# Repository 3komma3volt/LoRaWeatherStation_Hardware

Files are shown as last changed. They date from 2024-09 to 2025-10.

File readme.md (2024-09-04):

# LoRa Weather Station

The project was born for testing LoRa devices an has grown to a small weather station ecosystem.
Since August 2002, there are 6 station outside running without any maintenance. 

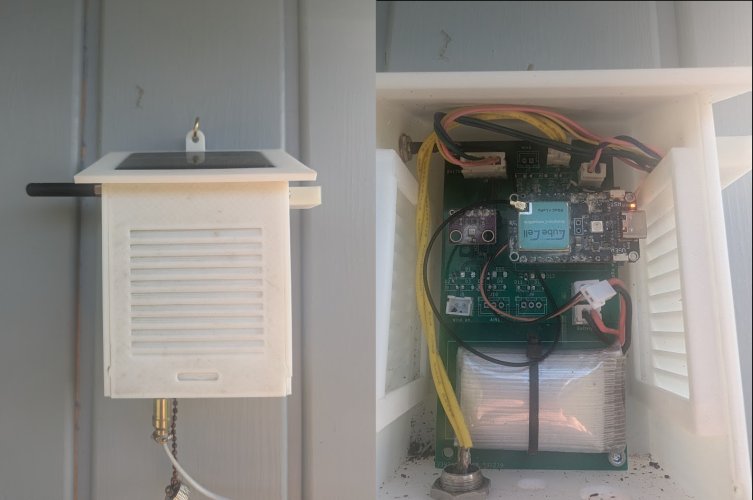
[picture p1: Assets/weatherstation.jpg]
Station


## Features

 - Completely 3D printed main body
 - Modular with optional extension
 - Simple PCB which can be hand assembled
 - Stations can be equipped with sensors as needed, they don't have to be the same kind
 - Using TheThingsStack for receiving data
 - Storage and analysis of data using a PHP framework (other repository)

## Housing

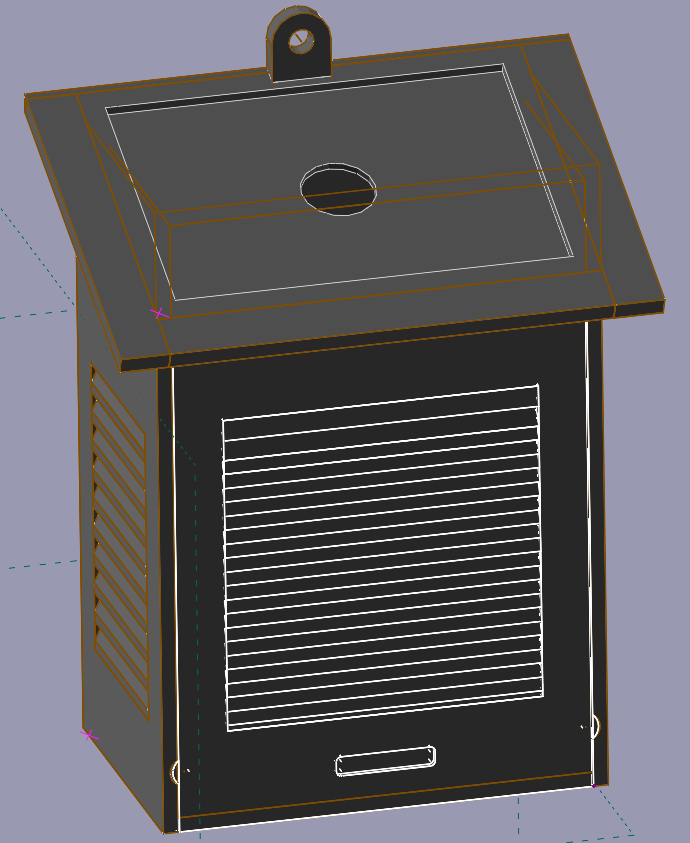
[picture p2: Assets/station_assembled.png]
Rendering


The main housing consists of:
 - Main housing
 - Front door
 - Sensor cover **or** light sensor mount
 - 2x side dust filter fixture
 - Front door dust filter fixture

On the sides and in the front door, there is the possibility to mount some 3mm fleece filters to prevent dust going into the housing and keep bugs out. A disadvantage is, that the inside gets a bit hotter if exposed to the sun.
The best mounting position of the station is 2m from the ground facing north and protected from sun exposure (The solar cell will get enough light to charge the battery).
A 80x55mm 7V solar cell is used to charge the battery. The solar cell is glued to the main body using silicone glue. This works great to keep rain out,
On the bottom is a intended breaking point to mount 12mm screw connectors for external sensors e.g. rain sensor or wind direction sensor.
On the left side is a hole for mounting a SMA connector for the LoRa antenna.
The housing can be mounted on a wall using a hook or screw.

## PCB
The PCB is kept simple, so it can be assembled by hand. It has to be screwed into the main body using **M3x8** (or similar length, there is plenty of space for longer screws)

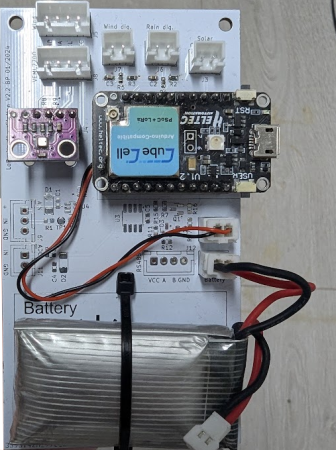
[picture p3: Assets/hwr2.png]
PCB


It is possible to use it just as carrier board, in this case, no component needs to be assembled.
For easier installation, XH connectors are used to connect sensors, battery, solar cell etc.
The CubeCell AB01 board is the brain of the weather station. It has a battery connector on its bottom side. For easier replacement of board or battery, this connector is connected with the PCB which again connects to the battery.
A BME280 board is connected using a standard header, so it can be replaced easily.

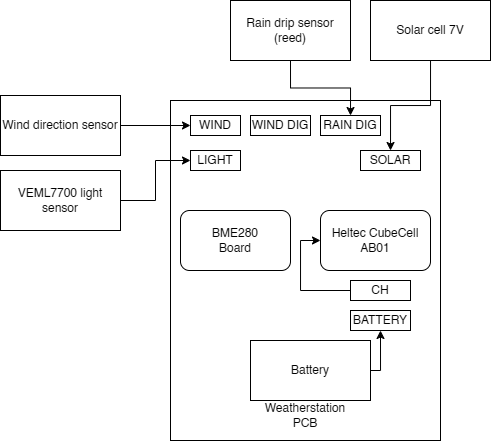
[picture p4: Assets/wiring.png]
Wiring


Two holes on the lower side of the PCB are for mounting a lithium battery using zip ties.
A  standard 1000mA 3.7V LIPO battery works great and never ran out even on cold and dark winter weeks.

## Wind Direction Sensor

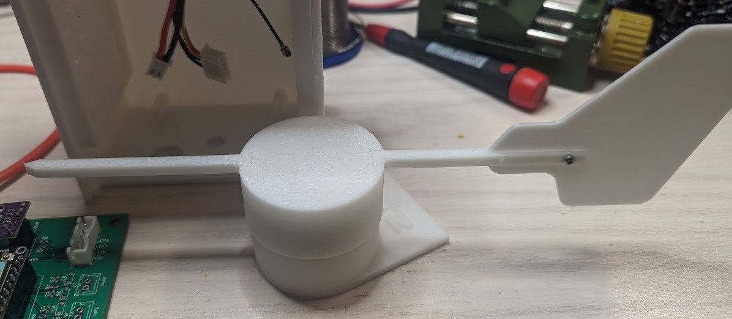
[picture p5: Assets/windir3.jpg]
Winddir


The wind direction sensor uses 8 reed contacts, a I2C port expander, a bearing (**608ZZ**) and a paddle to read the wind direction.

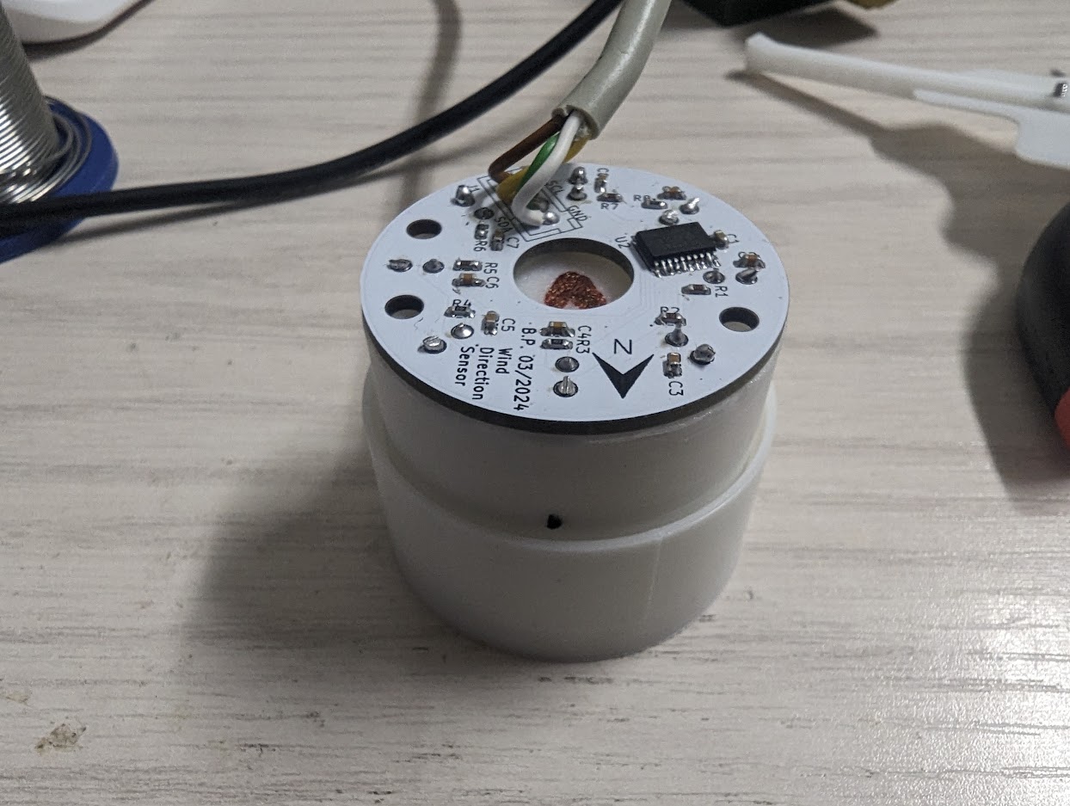
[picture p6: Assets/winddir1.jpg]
Winddir2


Only the expander and some few components need to be assembled.

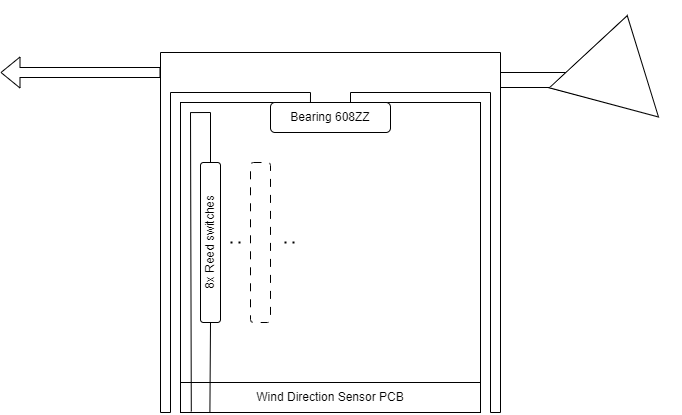
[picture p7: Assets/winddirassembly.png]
WindAssemly


The reed contacts are pushed through the sensor main body, On the upper side, a short wire has to be soldered to the reed contact and threaded through the second hole. The sensor and wire are then soldered to the sensor PCB.
A ⌀6x3mm magnet is glued into the sensor pin.

## Wind Speed Sensor

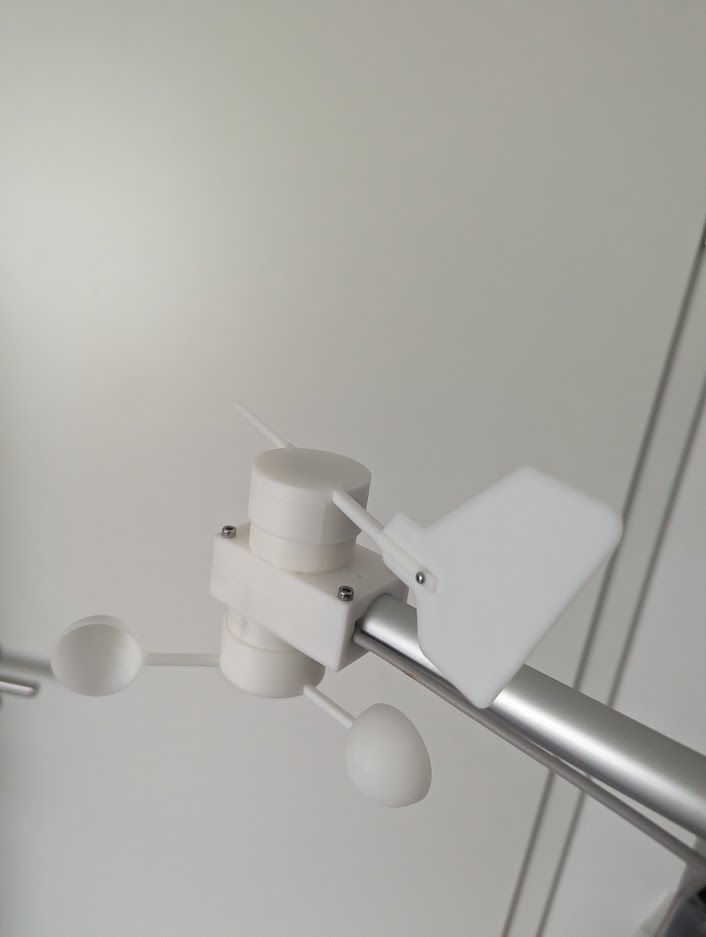
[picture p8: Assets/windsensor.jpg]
WindSpeedAndDir


The wind speed sensor using the same style bearing and manget like the direction sensor. It only consists of one reed contact. 
This sensor is an early alpha state, because the baring is to difficult to move and won't turn on low wind speeds. Maybe switching to a off-the-shelf product for this use case.

## Rain sensor

The 3D printed version of a rain sensor was not reliable enough. A cheap off the shelf sensor which is sold as spare part for weather stations works well. 

## Light sensor

A VEML7700 can be mounted on the side of the main body. For this print the mount and install the sensor within the mount. Fill up the space with transparent silicone. It will get watertight and works well. 

# Firmware
The firmware is made using PlatformIO and the Heltec development platform.
Simply open with VSCode and edit the platform.ini
You can change following build flags:

- ENABLE_RAINSENSOR=0 ; enables the rain drip sensor
- ENABLE_BRIGHTNESSENSOR=1 ; enables the brightness sensor
- ENABLE_WINDDIRSENSOR=0 ; enables the wind direction sensor
- ENABLE_WINDSPEEDSENSOR=0 ; enables the winds speed sensor
- DEBUG_UART=0  ; enables UART data sending for debug purposes

Enable the functionalities as wanted. 

>  Wind speed and direction are BETA!

As brightness sensor the VEML7700 is used. The BH1750 was also tested, but the results with this sensor were not really great. It was not really possible to get the cheap housing with the light dome watertight and several sensors died after a few days. If you want to use the BH1750, some changes in the code are necessary since this parts were removed.

Then hook up with TheThingsStack. There add a new device and get the neccessary data for OTAA transmission. Insert the information in the src/ttnparams.h file.

You probably will need a payload formatter for each individual weather station, since not all stations must have the same functionallity.

Here is a example formatter:

    function Decoder(bytes, port) {
    var temperature = (bytes[0] << 8 | bytes[1]);
	var humidity = (bytes[2] << 8 | bytes[3]);
    var pressure = ((bytes[4]) << 24) + ((bytes[5]) <<  16) + ((bytes[6]) << 8) + ((bytes[7]));
    var battery = (bytes[8] << 8) | bytes[9];
    var unused = (bytes[10] << 8) | bytes[11]; // formally used for battery percent calculation
    var brightness = (bytes[12] << 8) | bytes[13];
    var rain = bytes[14];
  
    var lux = brightness * 2.1504; // Datasheet: Gain 1/8, 25ms integration time
    lux = Math.round(6.0135e-13 * Math.pow(lux, 4) - 9.3924e-9 * Math.pow(lux, 3) + 8.1488e-5 * Math.pow(lux, 2) + 1.0023 * lux);
 
    var sensorSqure = 10.9 * 4.9; // for round rain sensors: sensorSqure = Math.PI * pow(sensorRadius, 2);
    var tipsPer100ml = 100 / 1.5;
    var mlPerTip = 100 / $tipsPer100ml;
    var rainAmount = $mlPerTip / $sensorSqure;
  
    return {
      temperature: temperature / 100,
      humidity: humidity,
      pressure: pressure / 100,
      battery: battery / 1000,
      brightness: lux,
      rain: rainAmount
      }
    }

If a station doesnt have a specific feature, just remove it from the return. The value has to be null to indicate, that the sensor is not available.

Example formatter for the most basic station just with a BME280:

    function Decoder(bytes, port) {
    var temperature = (bytes[0] << 8 | bytes[1]);
	var humidity = (bytes[2] << 8 | bytes[3]);
    var pressure = ((bytes[4]) << 24) + ((bytes[5]) <<  16) + ((bytes[6]) << 8) + ((bytes[7]));
    var battery = (bytes[8] << 8) | bytes[9];
    var unused = (bytes[10] << 8) | bytes[11]; // formally used for battery percent calculation

    return {
      temperature: temperature / 100,
      humidity: humidity,
      pressure: pressure / 100,
      battery: battery / 1000,
      }
    }

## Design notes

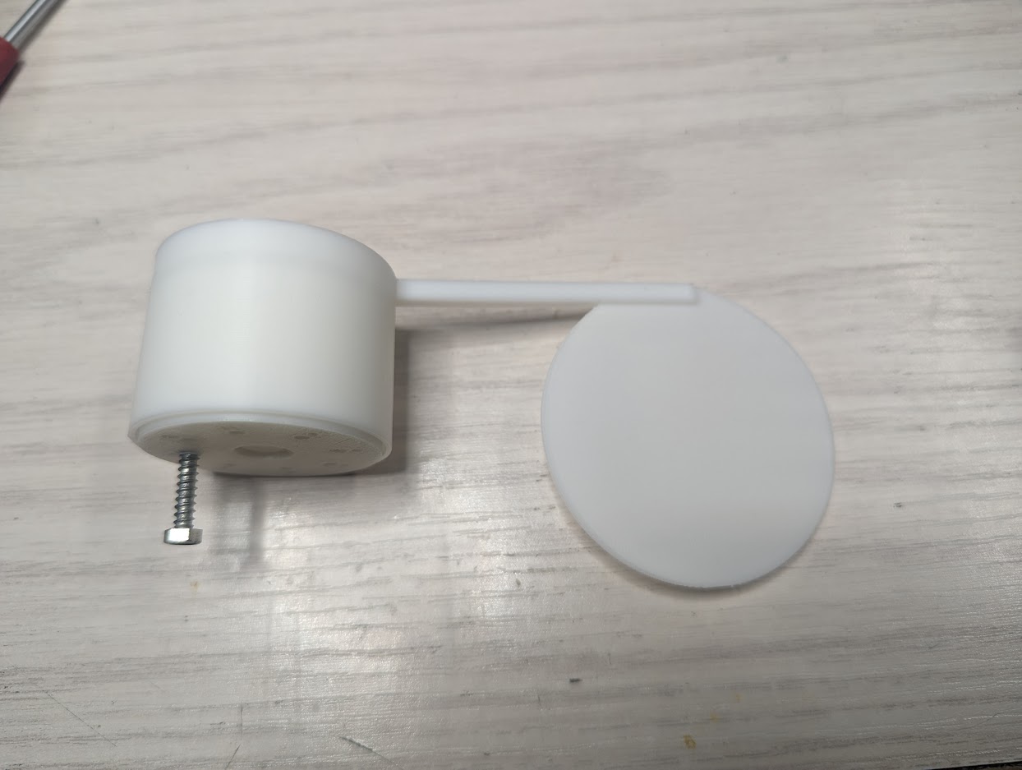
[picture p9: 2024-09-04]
Assets/winddir2.jpg

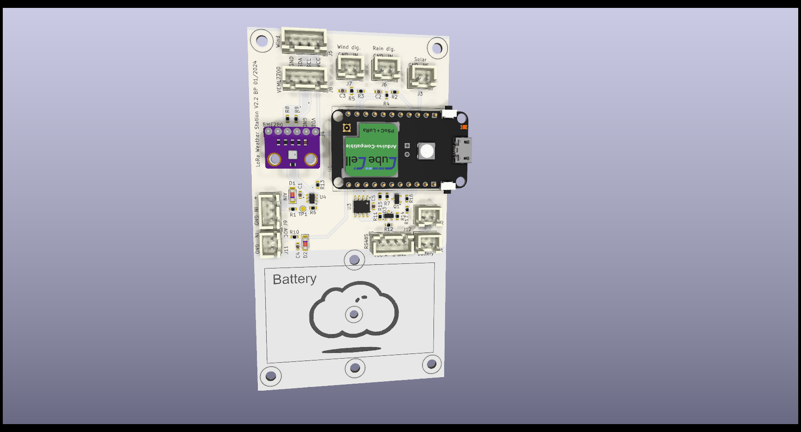
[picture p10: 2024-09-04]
Assets/loraWeatherstation.png

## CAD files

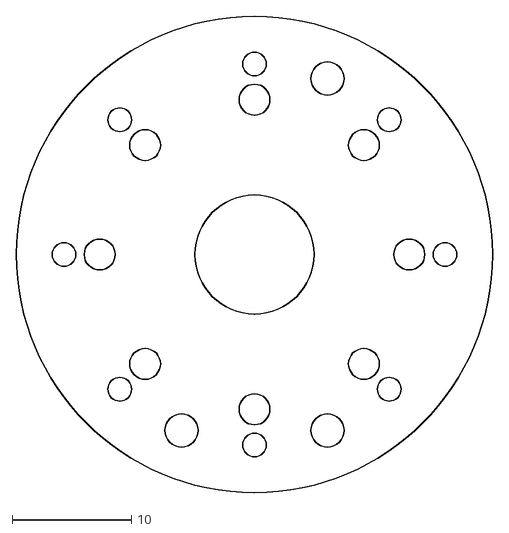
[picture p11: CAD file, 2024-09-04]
Schematics/WindDirSensor/mainbody.dxf
40.0 x 40.0

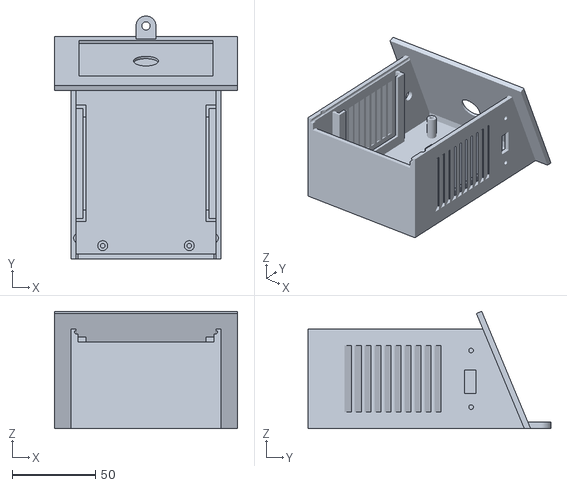
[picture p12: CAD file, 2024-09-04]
CAD/Weatherstation/stl/main_body.stl
110.0 x 146.0 x 70.6

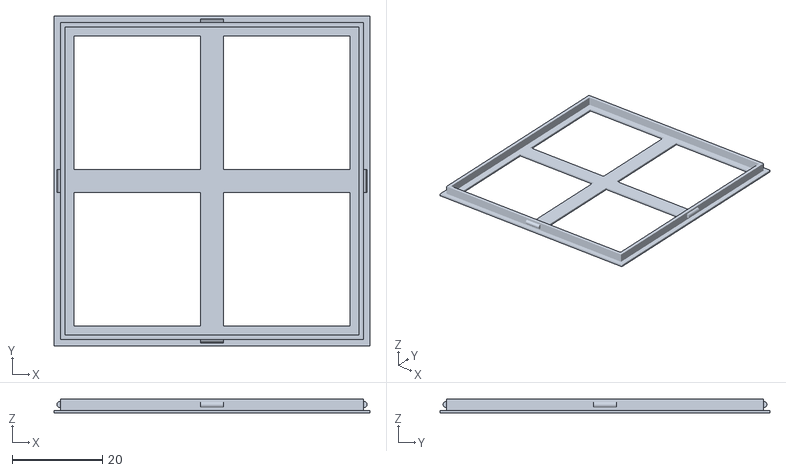
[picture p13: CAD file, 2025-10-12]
CAD/Weatherstation/stl/front_door_filter_fixture.stl
70.0 x 73.0 x 3.10

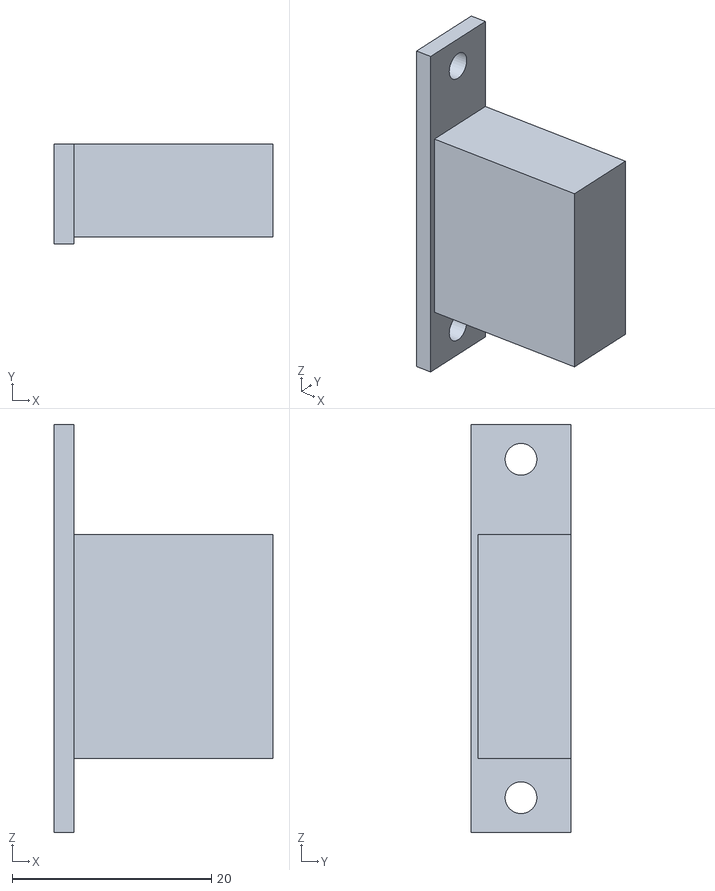
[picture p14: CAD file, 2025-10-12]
CAD/Weatherstation/stl/VEML7700_mount.stl
22.0 x 10.0 x 41.0

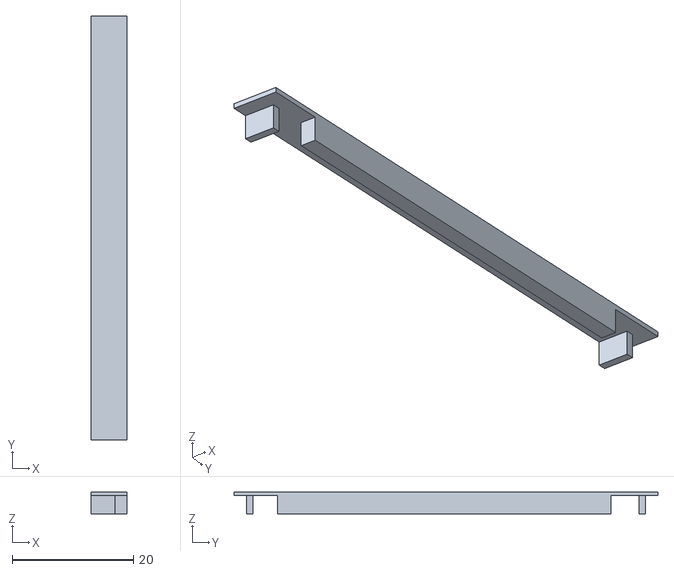
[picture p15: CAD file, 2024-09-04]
CAD/Weatherstation/stl/filterholder.stl
6.00 x 70.0 x 3.60

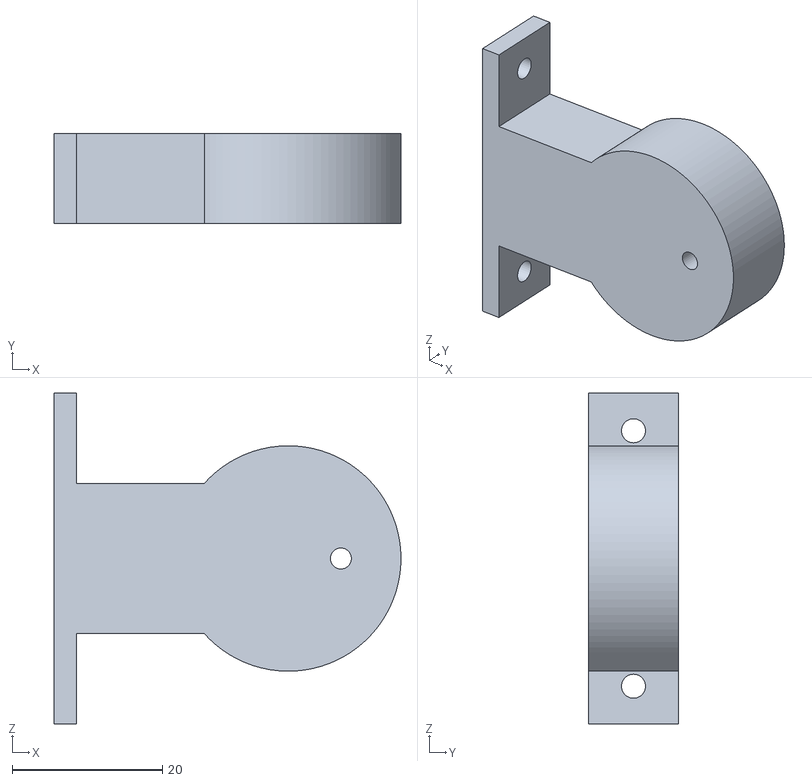
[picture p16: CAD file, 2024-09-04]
CAD/Weatherstation/stl/BH1750_mount.stl
46.2 x 12.0 x 44.0

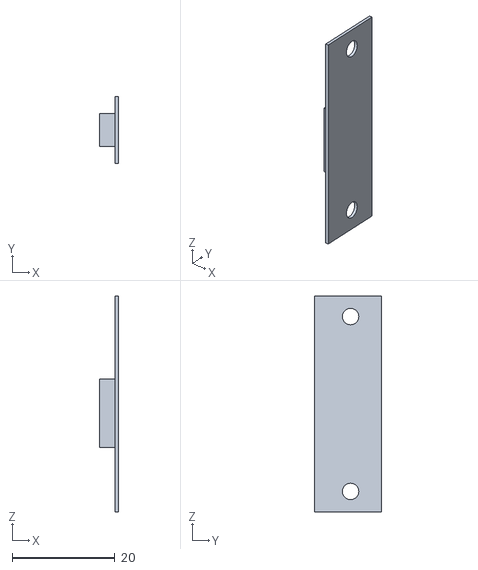
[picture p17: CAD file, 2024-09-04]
CAD/Weatherstation/stl/SideSensorCover.stl
3.60 x 13.0 x 42.0

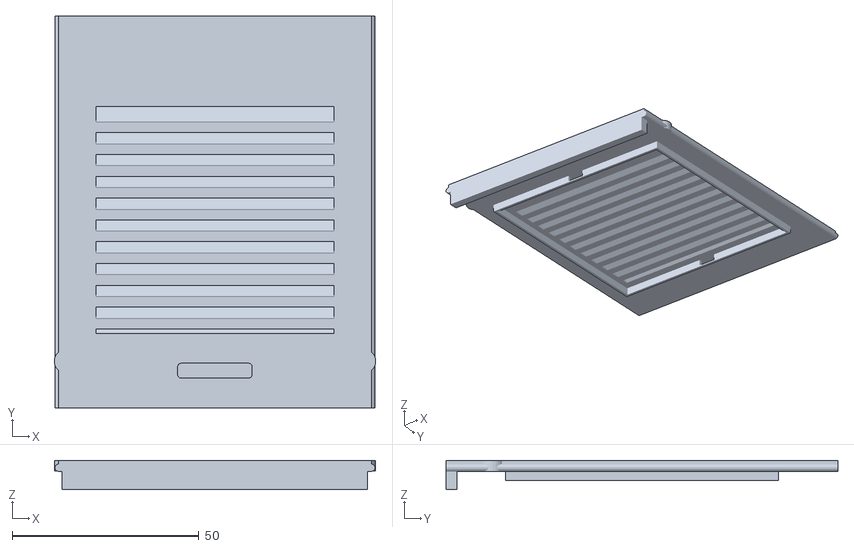
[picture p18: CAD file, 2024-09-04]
CAD/Weatherstation/stl/front_door.stl
86.1 x 105.0 x 7.90

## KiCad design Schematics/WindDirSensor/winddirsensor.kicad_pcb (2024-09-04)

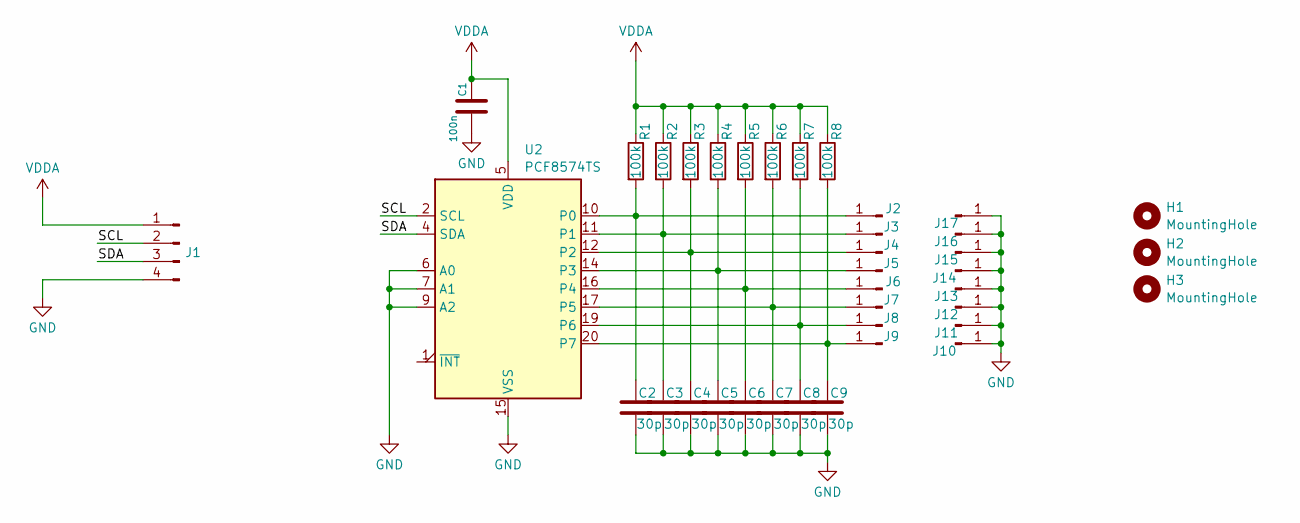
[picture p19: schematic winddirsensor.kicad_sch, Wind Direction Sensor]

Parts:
C1: 100n; C_0603_1608Metric; LCSC C14663
C2, C3, C4, C5, C6, C7, C8, C9: 30p; C_0603_1608Metric_Pad1.08x0.95mm_HandSolder; LCSC C1658
H1, H2, H3: MountingHole; MountingHole_3.2mm_M3
J1: Conn_01x04_Pin; JST_XH_B4B-XH-A_1x04_P2.50mm_Vertical
J2, J3, J4, J5, J6, J7, J8, J9, J10, J11, J12, J13, J14, J15, J16, J17: Conn_01x01_Pin; TestPoint_THTPad_D1.5mm_Drill0.7mm
R1, R2, R3, R4, R5, R6, R7, R8: 100k; R_0603_1608Metric; LCSC C25803
U2: PCF8574TS; SSOP-20_4.4x6.5mm_P0.65mm

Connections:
/SCL: J1.2, U2.2 (SCL)
/SDA: J1.3, U2.4 (SDA)
GND: C1.2, C2.2, C3.2, C4.2, C5.2, C6.2, C7.2, C8.2, C9.2, J1.4, J10.1, J11.1, J12.1, J13.1, J14.1, J15.1, J16.1, J17.1, U2.6 (A0), U2.7 (A1), U2.9 (A2), U2.15 (VSS)
unnamed: C2.1, J2.1, R1.2, U2.10 (P0)
unnamed: C3.1, J3.1, R2.2, U2.11 (P1)
unnamed: C4.1, J4.1, R3.2, U2.12 (P2)
unnamed: C5.1, J5.1, R4.2, U2.14 (P3)
unnamed: C6.1, J6.1, R5.2, U2.16 (P4)
unnamed: C7.1, J7.1, R6.2, U2.17 (P5)
unnamed: C8.1, J8.1, R7.2, U2.19 (P6)
unnamed: C9.1, J9.1, R8.2, U2.20 (P7)
VDDA: C1.1, J1.1, R1.1, R2.1, R3.1, R4.1, R5.1, R6.1, R7.1, R8.1, U2.5 (VDD)

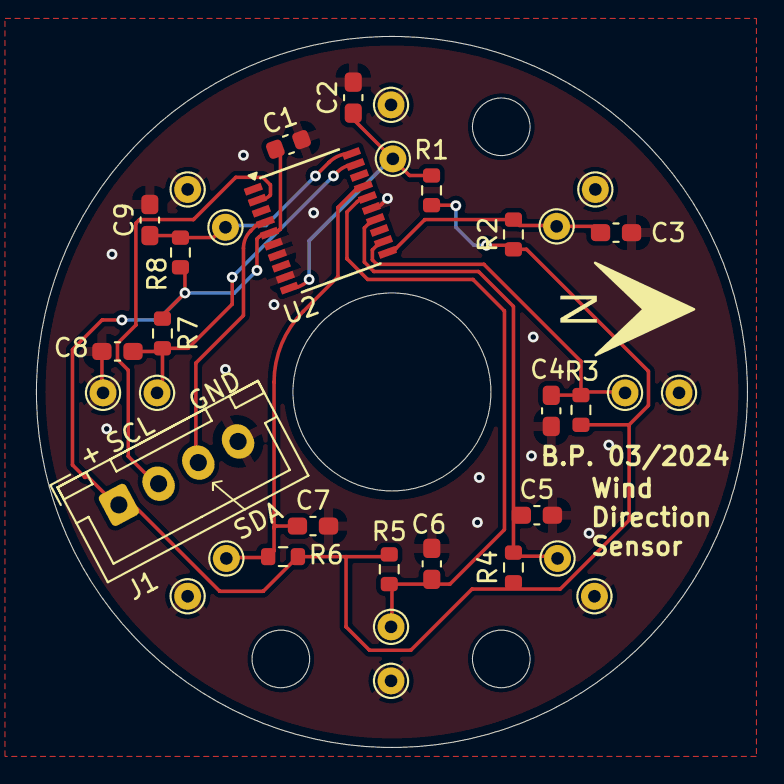
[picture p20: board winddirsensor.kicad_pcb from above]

Board: 2 copper layers, 39.5 x 39.5 mm, 38 parts (0 on the bottom side), 12 nets.

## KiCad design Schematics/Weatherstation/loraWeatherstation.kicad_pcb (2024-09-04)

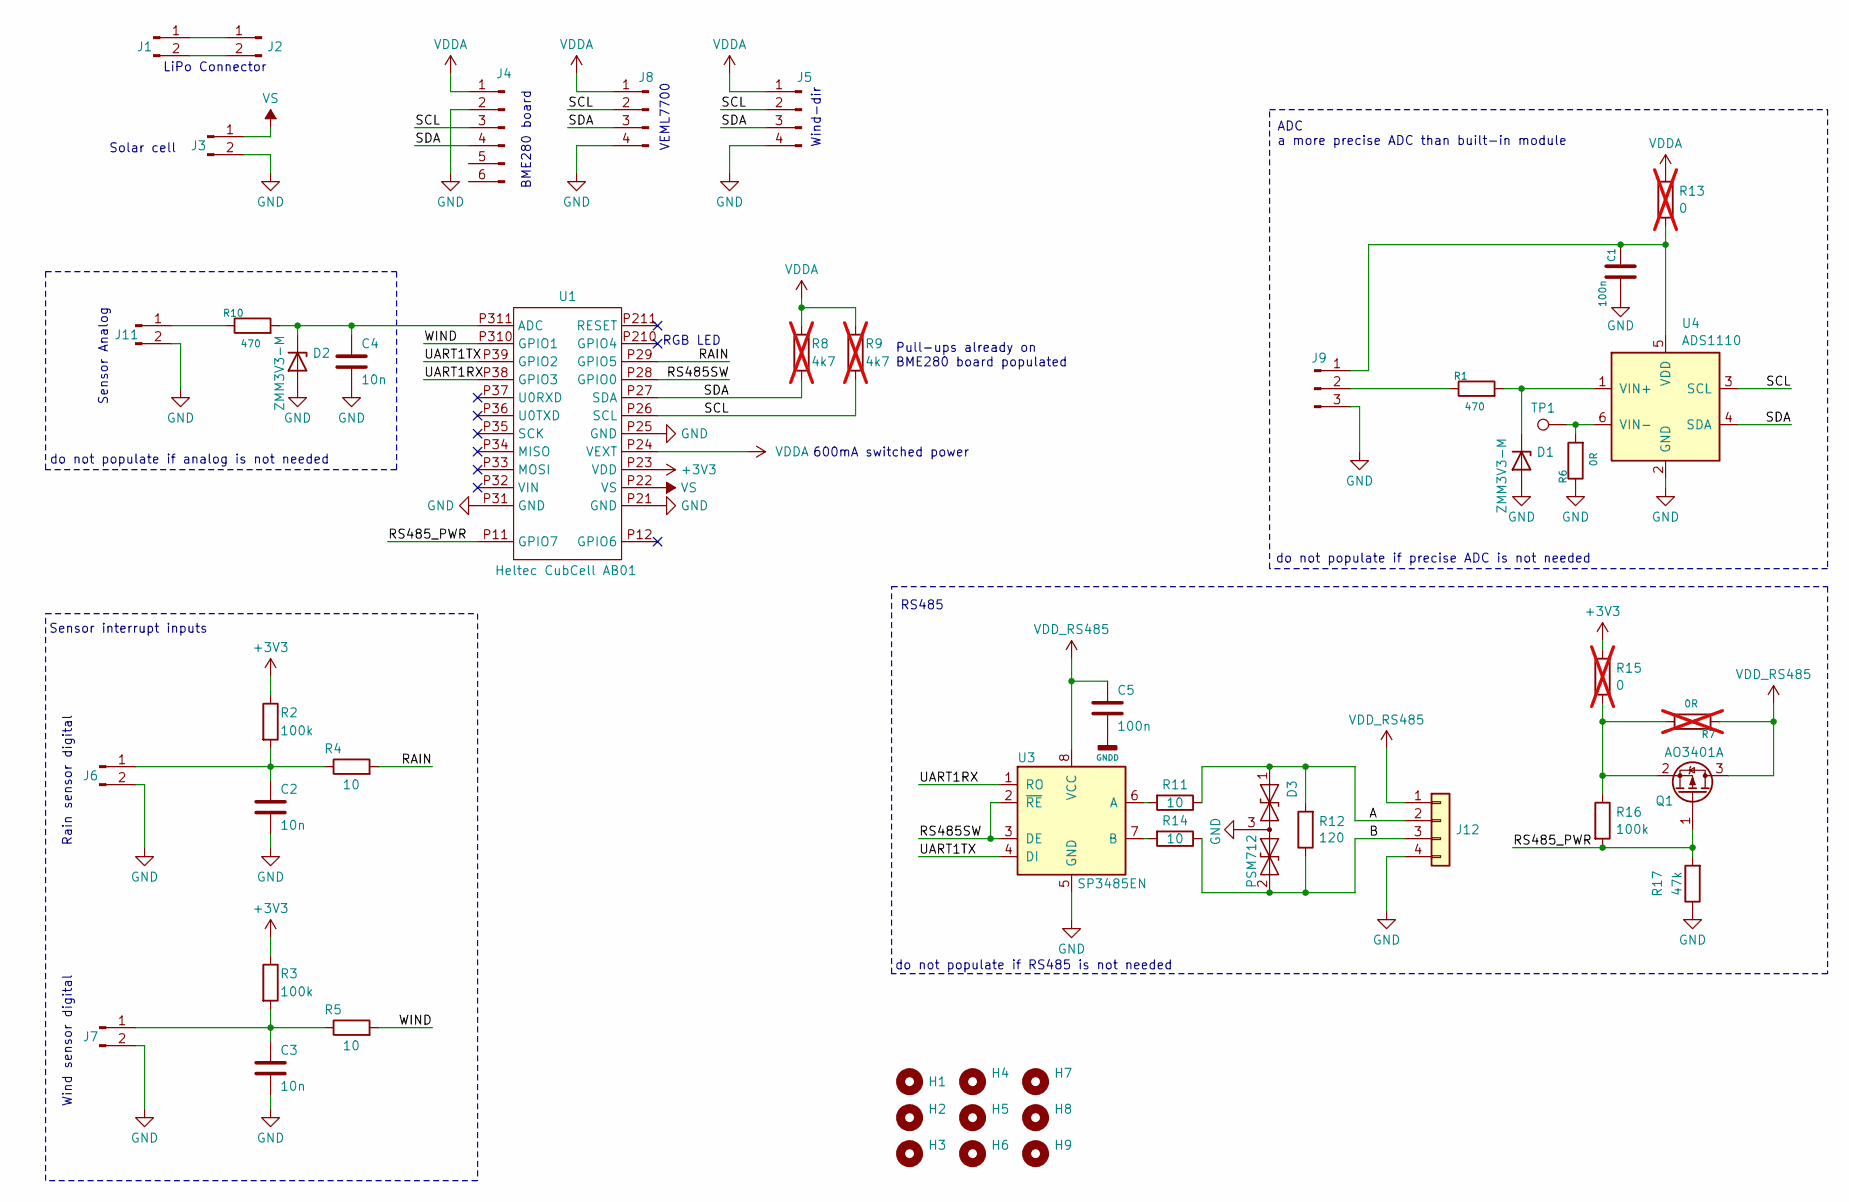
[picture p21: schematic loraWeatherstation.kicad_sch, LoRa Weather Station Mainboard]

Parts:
C1, C5: 100n; C_0603_1608Metric; LCSC C14663
C2, C3, C4: 10n; C_0603_1608Metric; LCSC C57112
D1, D2: ZMM3V3-M; D_MiniMELF; LCSC C8056
D3: PSM712; SOT-23; LCSC C32677
H1, H2, H3, H4, H5, H6: MountingHole; MountingHole_3.2mm_M3
H7, H8, H9: MountingHole; MountingHole_2.7mm
J1, J2, J3, J6, J7, J11: Conn_01x02_Pin; JST_XH_B2B-XH-A_1x02_P2.50mm_Vertical
J4: Conn_01x06_Pin; PinSocket_1x06_P2.54mm_Vertical
J5, J8: Conn_01x04_Pin; JST_XH_B4B-XH-A_1x04_P2.50mm_Vertical
J9: Conn_01x03_Pin; JST_XH_B3B-XH-A_1x03_P2.50mm_Vertical
J12: Conn_01x04; JST_XH_B4B-XH-A_1x04_P2.50mm_Vertical
Q1: AO3401A; SOT-23; LCSC C15127
R1, R10: 470; R_0603_1608Metric; LCSC C23182
R2, R3: 100k; R_0603_1608Metric; LCSC C25803
R4, R5, R11, R14: 10; R_0603_1608Metric; LCSC C22859
R6: 0R; R_0603_1608Metric
R7: 0R; R_0603_1608Metric; not fitted
R8, R9: 4k7; R_0603_1608Metric; LCSC C23162; not fitted
R12: 120; R_0603_1608Metric; LCSC C22787
R13, R15: 0; R_0603_1608Metric; not fitted
R16: 100k; R_0603_1608Metric; LCSC C22936
R17: 47k; R_0603_1608Metric; LCSC C25819
TP1: TestPoint; TestPoint_Pad_D1.5mm
U1: Heltec CubCell AB01; CubeCellAB01
U3: SP3485EN; SOIC-8_3.9x4.9mm_P1.27mm; LCSC C8963
U4: ADS1110; SOT-23-6

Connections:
+3V3: R2.1, R3.1, R15.1, U1.P23 (VDD)
/A: D3.1 (A1), J12.2, R11.1, R12.2
/B: D3.2 (A2), J12.3, R12.1, R14.1
/RAIN: R4.2, U1.P29 (GPIO5)
/RS485SW: U1.P28 (GPIO0), U3.2 (~RE), U3.3 (DE)
/RS485_PWR: Q1.1 (G), R16.2, R17.2, U1.P11 (GPIO7)
/SCL: J4.3, J5.2, J8.2, R9.2, U1.P26 (SCL), U4.3 (SCL)
/SDA: J4.4, J5.3, J8.3, R8.2, U1.P27 (SDA), U4.4 (SDA)
/UART1RX: U1.P38 (GPIO3), U3.1 (RO)
/UART1TX: U1.P39 (GPIO2), U3.4 (DI)
/WIND: R5.2, U1.P310 (GPIO1)
GND: C1.2, C2.2, C3.2, C4.2, D1.2 (A), D2.2 (A), D3.3 (common), J3.2, J4.2, J5.4, J6.2, J7.2, J8.4, J9.3, J11.2, J12.4, R6.1, R17.1, U1.P21 (GND), U1.P25 (GND), U1.P31 (GND), U3.5 (GND), U4.2 (GND)
GNDD: C5.2
unnamed: D1.1 (K), R1.2, U4.1 (VIN+)
unnamed: C4.1, D2.1 (K), R10.2, U1.P311 (ADC)
unnamed: J1.1, J2.1
unnamed: J1.2, J2.2
unnamed: C2.1, J6.1, R2.2, R4.1
unnamed: C3.1, J7.1, R3.2, R5.1
unnamed: C1.1, J9.1, R13.2, U4.5 (VDD)
unnamed: J9.2, R1.1
unnamed: J11.1, R10.1
unnamed: Q1.2 (S), R7.2, R15.2, R16.1
unnamed: R11.2, U3.6 (A)
unnamed: R14.2, U3.7 (B)
unnamed: R6.2, TP1.1, U4.6 (VIN-)
VDDA: J4.1, J5.1, J8.1, R8.1, R9.1, R13.1, U1.P24 (VEXT)
VDD_RS485: C5.1, J12.1, Q1.3 (D), R7.1, U3.8 (VCC)
VS: J3.1, U1.P22 (VS)

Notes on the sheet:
do not populate if precise ADC is not needed
Rain sensor digital
ADC a more precise ADC than built-in module
do not populate if RS485 is not needed
Solar cell
Pull-ups already on BME280 board populated
Sensor interrupt inputs
do not populate if analog is not needed
RS485
RGB LED
BME280 board
600mA switched power
Wind-dir
Wind sensor digital
LiPo Connector
Sensor Analog
VEML7700

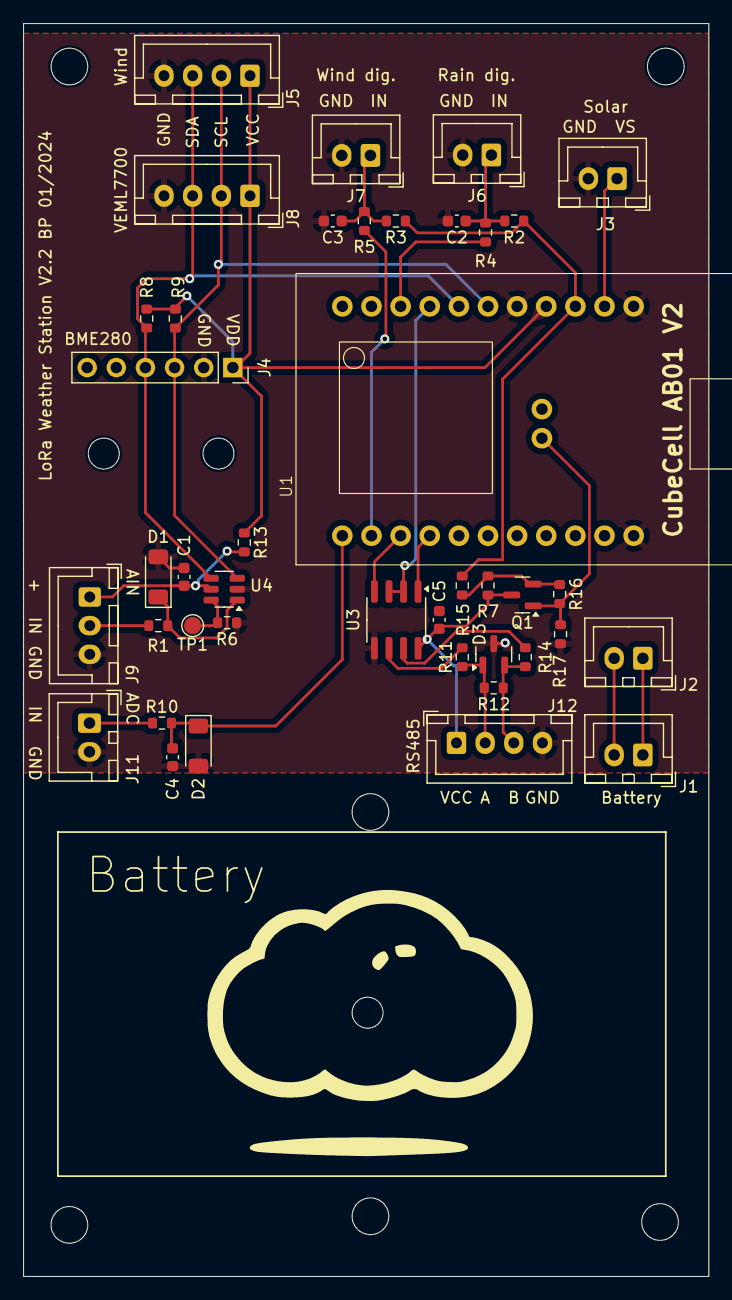
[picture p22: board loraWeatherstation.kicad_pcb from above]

Board: 2 copper layers, 59.8 x 109.2 mm, 50 parts (0 on the bottom side), 28 nets.

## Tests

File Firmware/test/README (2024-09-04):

function Decoder(bytes, port) {
  var temperature = bytes[0]<<24>>16 | bytes[1];
  var humidity = (bytes[2] << 8) | bytes[3];
  var pressure = ((bytes[4]) << 24) + ((bytes[5]) << 16) + ((bytes[6]) << 8) + ((bytes[7]));
  var battery = (bytes[8] << 8) | bytes[9];
  var unused = (bytes[10] << 8) | bytes[11];
  var brightness = (bytes[12] << 8) | bytes[13];
  var rain = bytes[14];
  
  return {
    temperature: temperature / 100,
    humidity: humidity,
    pressure: pressure / 100,
    battery: battery / 1000,
    brightness: brightness,
    rain: rain
  }
}

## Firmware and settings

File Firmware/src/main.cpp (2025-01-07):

#include <Arduino.h>
#include <LoRaWan_APP.h>
#include <Wire.h>

#include "Light_VEML7700.h"
#include "PCF8574.h"
#include "Seeed_BME280.h"
#include "ttnparams.h"

uint32_t appTxDutyCycle = 10 * 60000;  // the frequency of readings, in minutes * 60000

LoRaMacRegion_t loraWanRegion = ACTIVE_REGION;
DeviceClass_t loraWanClass = LORAWAN_CLASS;
bool overTheAirActivation = LORAWAN_NETMODE;
bool loraWanAdr = LORAWAN_ADR;
bool keepNet = LORAWAN_NET_RESERVE;
bool isTxConfirmed = LORAWAN_UPLINKMODE;
uint8_t appPort = 2;
uint8_t confirmedNbTrials = 4;

int temperature, humidity, batteryVoltage, batteryLevel;

long pressure;

BME280 bme280;

#if ENABLE_WINDSPEEDSENSOR == 1
volatile uint16_t windspeed;
#define WINDPIN GPIO1
#endif

#if ENABLE_BRIGHTNESSENSOR == 1
uint8_t sensor_available_brightness = 0;
uint16_t brightness;
Light_VEML7700 veml7700 =
    Light_VEML7700();  // Or change to use the BH1750, but this sensor did not
                       // work very well
#endif

#if ENABLE_WINDDIRSENSOR == 1
uint8_t sensor_winddir_available = 0;
uint8_t wind_direction = 0;
#endif

#if ENABLE_RAINSENSOR == 1
#define RAIN_PIN GPIO5
volatile uint8_t rain;
#endif

static void prepareTxFrame(uint8_t port) {
  pinMode(Vext, OUTPUT);
  digitalWrite(Vext, LOW);

#if ENABLE_WINDSPEEDSENSOR == 1
  windspeed = 0;
  pinMode(WINDPIN, INPUT);
  attachInterrupt(WINDPIN, windcounter, FALLING);
#endif

  delay(500);
  // Wire.begin(SDA, SCL);
  if (!bme280.init()) {
#if DEBUG_UART == 1

    Serial.println("Device error!");
#endif
  }

#if ENABLE_BRIGHTNESSENSOR == 1
  if (veml7700.begin()) {
#if DEBUG_UART == 1
    Serial.println(F("VEML7700 Advanced begin"));
#endif
    veml7700.setGain(VEML7700_GAIN_1_8);
    veml7700.setIntegrationTime(VEML7700_IT_25MS);
    sensor_available_brightness = 1;
  } else {
#if DEBUG_UART == 1
    Serial.println(F("Error initialising VEML7700"));
#endif
    appData[12] = 0xFF;  // brightness high
    appData[13] = 0xFF;  // bightness low
    sensor_available_brightness = 0;
  }
#endif

#if ENABLE_WINDDIRSENSOR == 1
  if (PCF8574_Init(0x20)) {
    sensor_winddir_available = 1;
#if DEBUG_UART == 1
    Serial.println("Init Winddirsensor PCF8574");
#endif
  } else {
    sensor_winddir_available = 0;
#if DEBUG_UART == 1
    Serial.println("Failed Winddirsensor PCF8574");
    appData[15] = 0;
#endif
  }

#endif

  delay(500);  // Time for sensor init
#if ENABLE_WINDSPEEDSENSOR == 1
  detachInterrupt(WINDPIN);
#endif

  temperature = bme280.getTemperature() * 100;
  humidity = bme280.getHumidity();
  pressure = bme280.getPressure();

#if ENABLE_BRIGHTNESSENSOR == 1
  if (sensor_available_brightness == 1) {
    brightness = veml7700.readALS();
  }
#endif

#if ENABLE_WINDDIRSENSOR == 1
  if (sensor_winddir_available == 1) {
    wind_direction = PCF8574_Read(0x20);
  }
#endif

  Wire.end();

  digitalWrite(Vext, HIGH);

  batteryVoltage = getBatteryVoltage();
  // batteryLevel = (BoardGetBatteryLevel() / 254) * 100;

  appDataSize = 17;

  appData[0] = highByte(temperature);
  appData[1] = lowByte(temperature);

  appData[2] = highByte(humidity);
  appData[3] = lowByte(humidity);

  appData[4] = (byte)((pressure & 0xFF000000) >> 24);
  appData[5] = (byte)((pressure & 0x00FF0000) >> 16);
  appData[6] = (byte)((pressure & 0x0000FF00) >> 8);
  appData[7] = (byte)((pressure & 0X000000FF));

  appData[8] = highByte(batteryVoltage);
  appData[9] = lowByte(batteryVoltage);

  appData[10] = 0xFF;  // old batterylevel
  appData[11] = 0xFF;  // old batterylevel
#if ENABLE_BRIGHTNESSENSOR == 1
  appData[12] = highByte(brightness);  // brightness high
  appData[13] = lowByte(brightness);   // bightness low
#else
  appData[12] = 0xFF;
  appData[13] = 0xFF;
#endif
#if ENABLE_RAINSENSOR == 1
  appData[14] = rain;  // rain value
#else
  appData[14] = 0xFF;
#endif
#if ENABLE_WINDDIRSENSOR == 1
  appData[15] = wind_direction;
#else
  appData[15] = 0;
#endif
#if ENABLE_WINDSPEEDSENSOR == 1
  appData[16] = windspeed;
#else
  appData[16] = 0xFF;
#endif

#if DEBUG_UART == 1
  Serial.print("Temperature: ");
  Serial.print(temperature / 100);
  Serial.print("C, Humidity: ");
  Serial.print(humidity);
  Serial.print("%, Pressure: ");
  Serial.print(pressure / 100);
  Serial.print(" mbar, Battery Voltage: ");
  Serial.print(batteryVoltage);
  Serial.print(" mV, Battery Level: ");
  Serial.print(batteryLevel);
  Serial.print(" %, Brightness: ");
  Serial.print(brightness);
  #if ENABLE_RAINSENSOR == 1
  Serial.print(" lx, Rain: ");
  Serial.print(rain);
Serial.print(" cts, ");
  #endif
  #if ENABLE_WINDDIRSENSOR == 1
  Serial.print("Winddir: ");
  Serial.print(wind_direction, BIN);
  Serial.print(" dir ");
  #endif

  Serial.print("\n");

#endif

#if ENABLE_RAINSENSOR == 1
  rain = 0;
#endif
}

#if ENABLE_WINDSPEEDSENSOR == 1
void windcounter() { windspeed++; }
#endif

#if ENABLE_RAINSENSOR == 1
void raincounter() {
  // Serial.println(rain);
  static unsigned long last_interrupt_time = 0;
  unsigned long interrupt_time = millis();
  if (interrupt_time - last_interrupt_time > 200) {
    rain = rain + 1;
  }
  last_interrupt_time = interrupt_time;
  rain = rain + 1;
}

#endif

void setup() {
  boardInitMcu();
#if DEBUG_UART == 1

  Serial.begin(115200);
#endif
#if ENABLE_RAINSENSOR == 1
  pinMode(RAIN_PIN, INPUT);
  attachInterrupt(RAIN_PIN, raincounter, FALLING);
#endif

  deviceState = DEVICE_STATE_INIT;
  LoRaWAN.ifskipjoin();
}

void loop() {
#if DEBUG_UART == 1
  prepareTxFrame(2);
#else
  if (true) {
    switch (deviceState) {
      case DEVICE_STATE_INIT: {
        printDevParam();
        LoRaWAN.init(loraWanClass, loraWanRegion);
        deviceState = DEVICE_STATE_JOIN;
        break;
      }
      case DEVICE_STATE_JOIN: {
        LoRaWAN.join();
        deviceState = DEVICE_STATE_CYCLE;
        break;
      }
      case DEVICE_STATE_SEND: {
        prepareTxFrame(appPort);
        LoRaWAN.send();
        deviceState = DEVICE_STATE_CYCLE;
        break;
      }
      case DEVICE_STATE_CYCLE: {
        // Schedule next packet transmission
        txDutyCycleTime = appTxDutyCycle + randr(0, APP_TX_DUTYCYCLE_RND);
        LoRaWAN.cycle(txDutyCycleTime);
        deviceState = DEVICE_STATE_SLEEP;
        break;
      }
      case DEVICE_STATE_SLEEP: {
        LoRaWAN.sleep();
        break;
      }
      default: {
        deviceState = DEVICE_STATE_INIT;
        break;
      }
    }
  }
#endif
}

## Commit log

2025-01-07 Fixed printing of undefined sensors
    [main.cpp]
2025-10-12 Improved front door filter mount for better mount Made VEML7700 a bit higher for better water tightness
    [VEML7700_mount.stl, front_door_filter_fixture.stl]
